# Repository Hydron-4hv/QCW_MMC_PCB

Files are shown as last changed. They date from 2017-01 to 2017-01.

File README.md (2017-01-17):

# QCW_MMC_PCB
PCB for MMC for QCW DRSSTC

- PCB for 12.4nF/6.4kV MMC using 32x 6.2nF/1600V B32672 TDK EPCOS capacitors. Can fit other 15mm lead spacing capacitors (e.g. up to 32x 15nF/1600V in B32672 series, or using every second row, up to 16x 33nF/1600V).
- Suggest using 2x >5Mohm 1206 High Voltage SMD resistors for bleed/balance across each capacitor (footprints provided on underside).
  - Note that when MMC capacitors with rating >~800V are used (and run near their DC rating) it is likely that the resistors will end up having voltage applied greater than their normal "working voltage".
  - "High Voltage" rated resistors are available, and should have an "overload" voltage rating significantly greater than their working voltage.
  - It may be OK to run at the "overload" rating in tesla coil duty, but is at your own risk.
- Footprints provided for optional Wurth Electronics press-fit connectors (assumes HASL PCB finish), as well as various holes for screw-down terminations
- Intended for use by itself (using 1 or more PCBs depending on requirement), or in conjuction with PCBs located in the "GDT_PCB" and "QCW_half_bridge_PCB" repos.

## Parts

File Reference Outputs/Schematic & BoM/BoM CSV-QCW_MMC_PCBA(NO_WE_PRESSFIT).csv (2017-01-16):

Designator | Comment | Description | Fitted | Footprint | LibRef | Quantity
C1, C2, C3, C4, C5, C6, C7, C8, C9, C10, C11, C12, C13, C14, C15, C16, C17, C18, C19, C20, C21, C22, C23, C24, C25, C26, C27, C28, C29, C30, C31, C32 | B32672 | Capacitor | Fitted | B32672 6n2 1600V | Cap | 32
E1, E2, E3, E4 | 7461111 | WP-RAFU 90° with Full Plain Pin Plate, M4, thr 5mm | Not Fitted | 7461111_HAL Surface | WP-RAFU, 7461111 | 0
R1, R2, R3, R4, R5, R6, R7, R8, R9, R10, R11, R12, R13, R14, R15, R16, R17, R18, R19, R20, R21, R22, R23, R24, R25, R26, R27, R28, R29, R30, R31, R32, R33, R34, R35, R36, R37, R38, R39, R40, R41, R42, R43, R44, R45, R46, R47, R48, R49, R50, R51, R52, R53, R54, R55, R56, R57, R58, R59, R60, R61, R62, R63, R64 | HV 1206 Resistor | Resistor | Fitted | RES_1206_HV | Res3 | 64

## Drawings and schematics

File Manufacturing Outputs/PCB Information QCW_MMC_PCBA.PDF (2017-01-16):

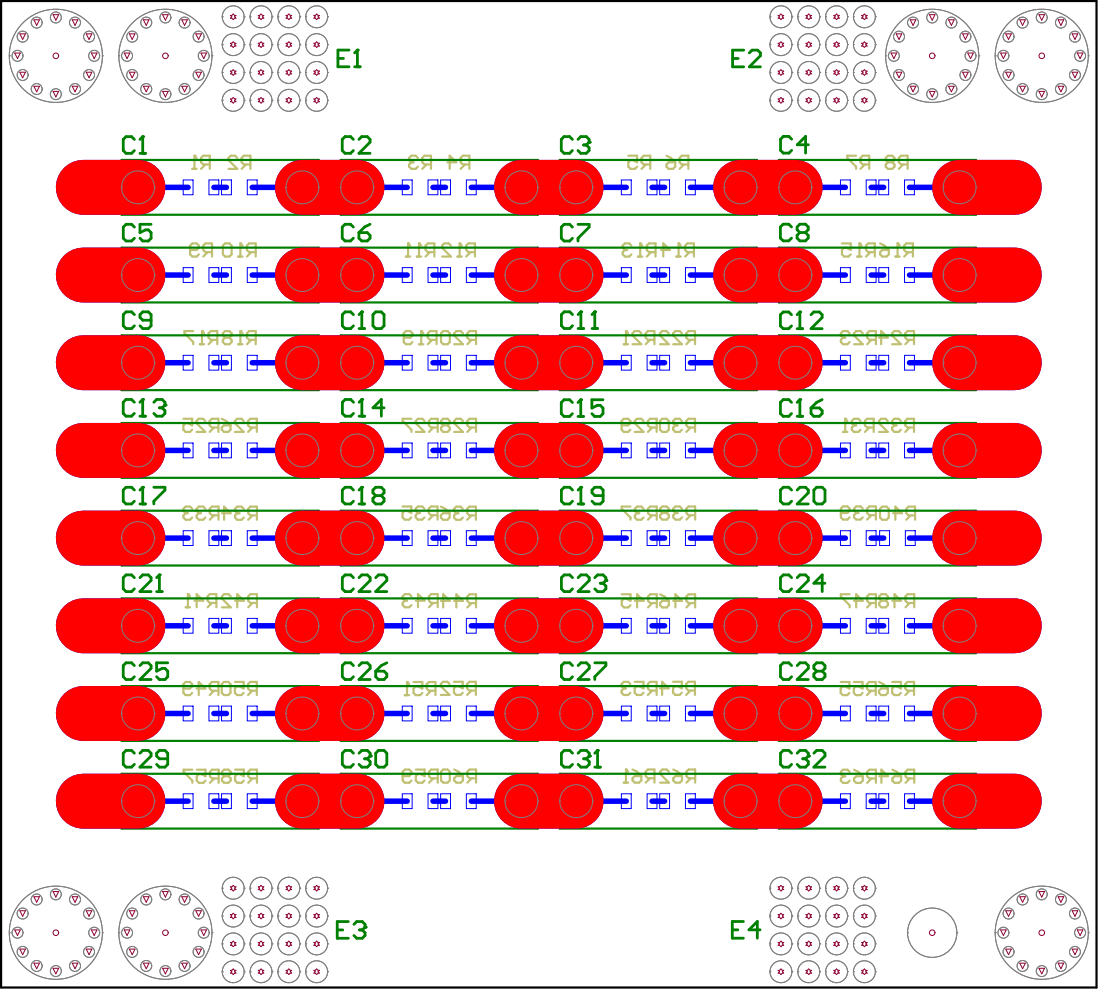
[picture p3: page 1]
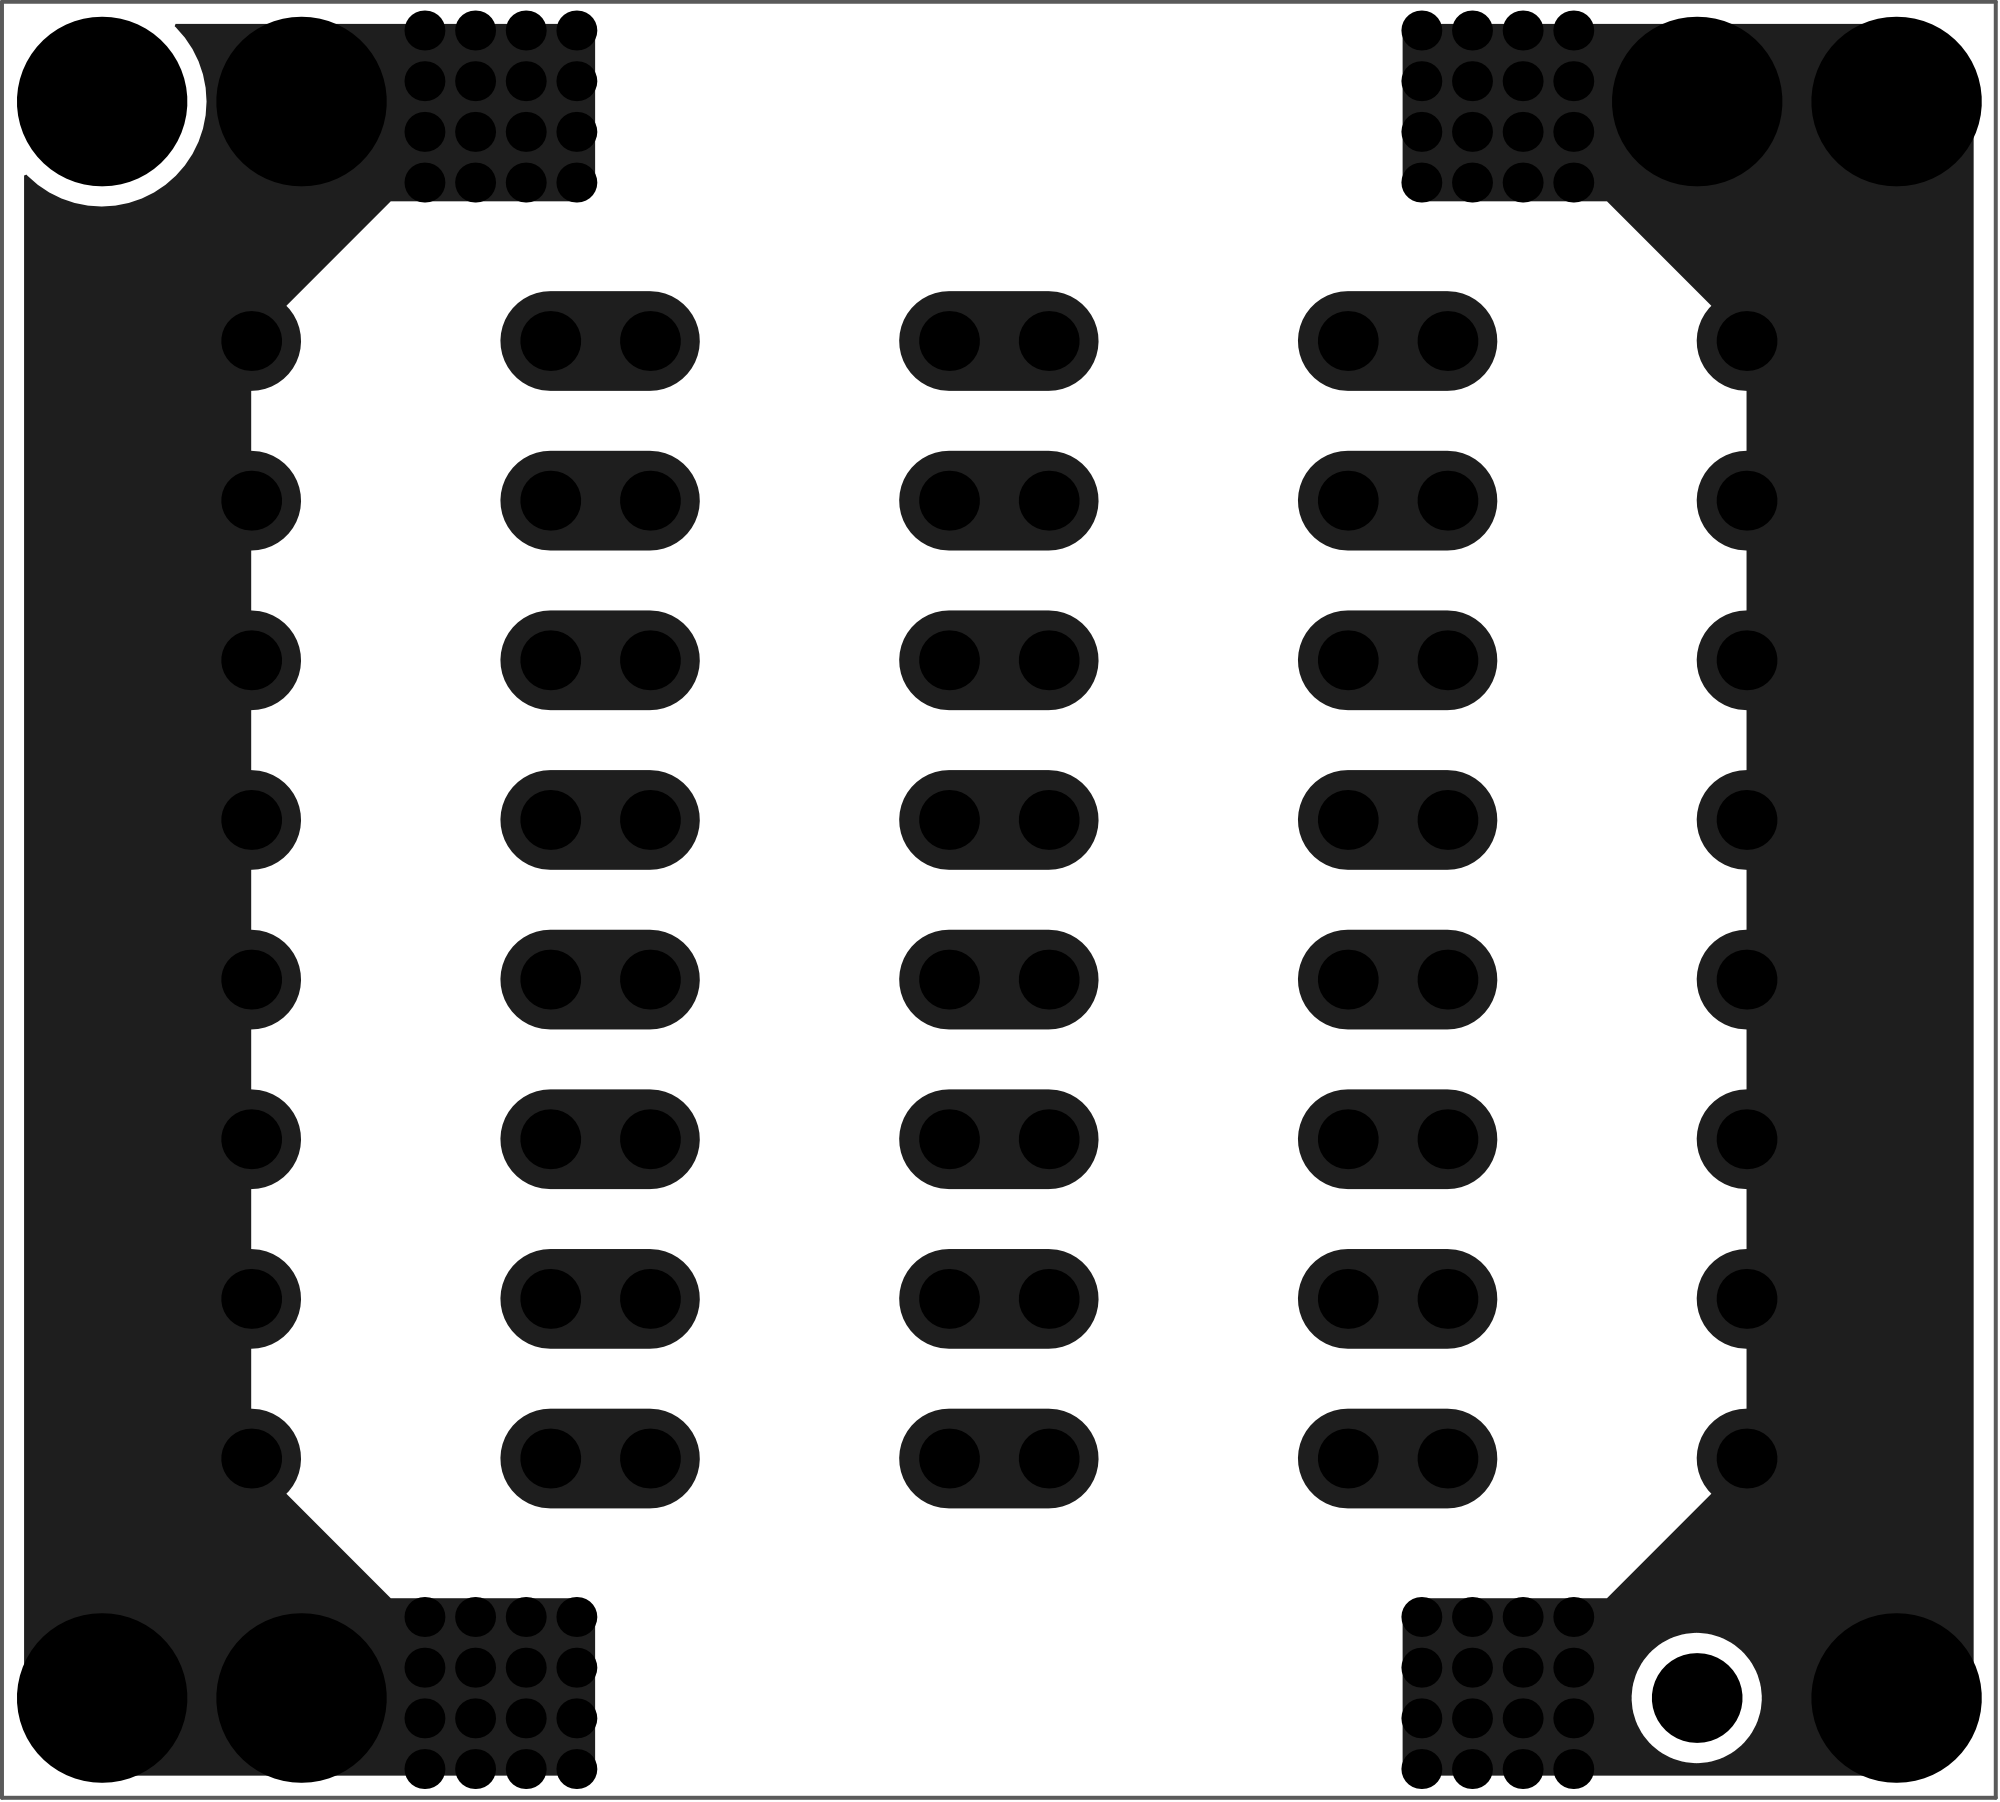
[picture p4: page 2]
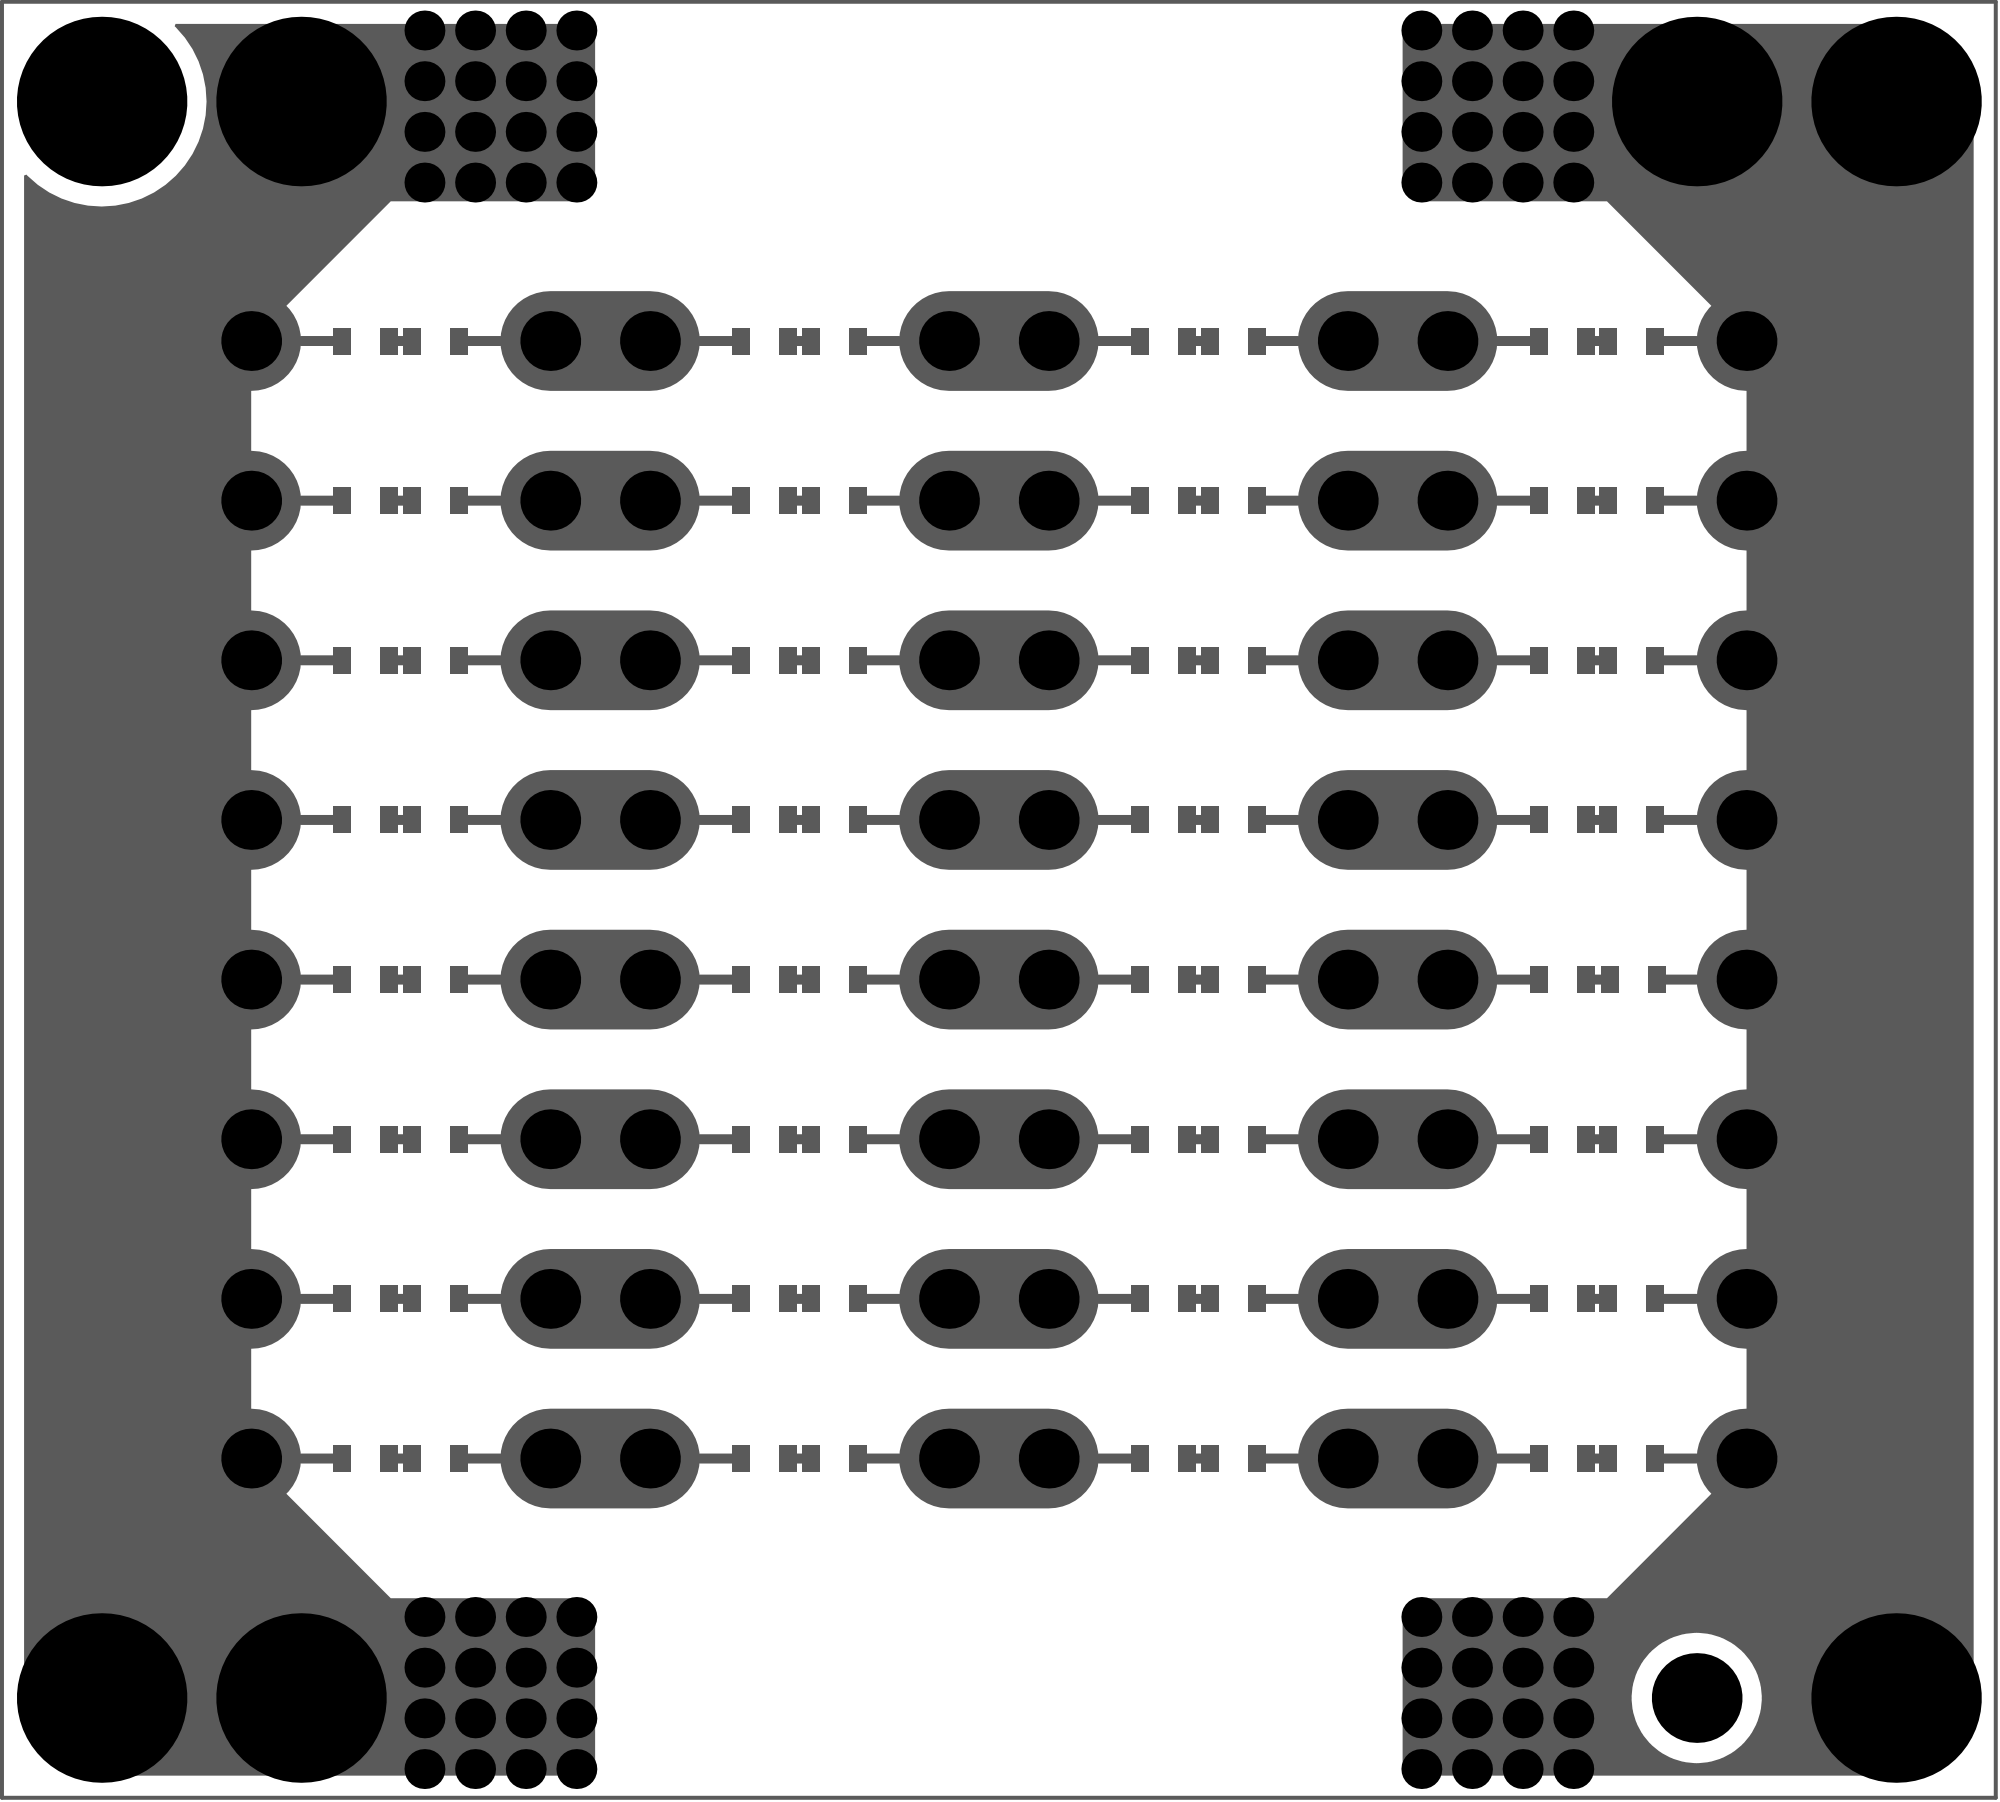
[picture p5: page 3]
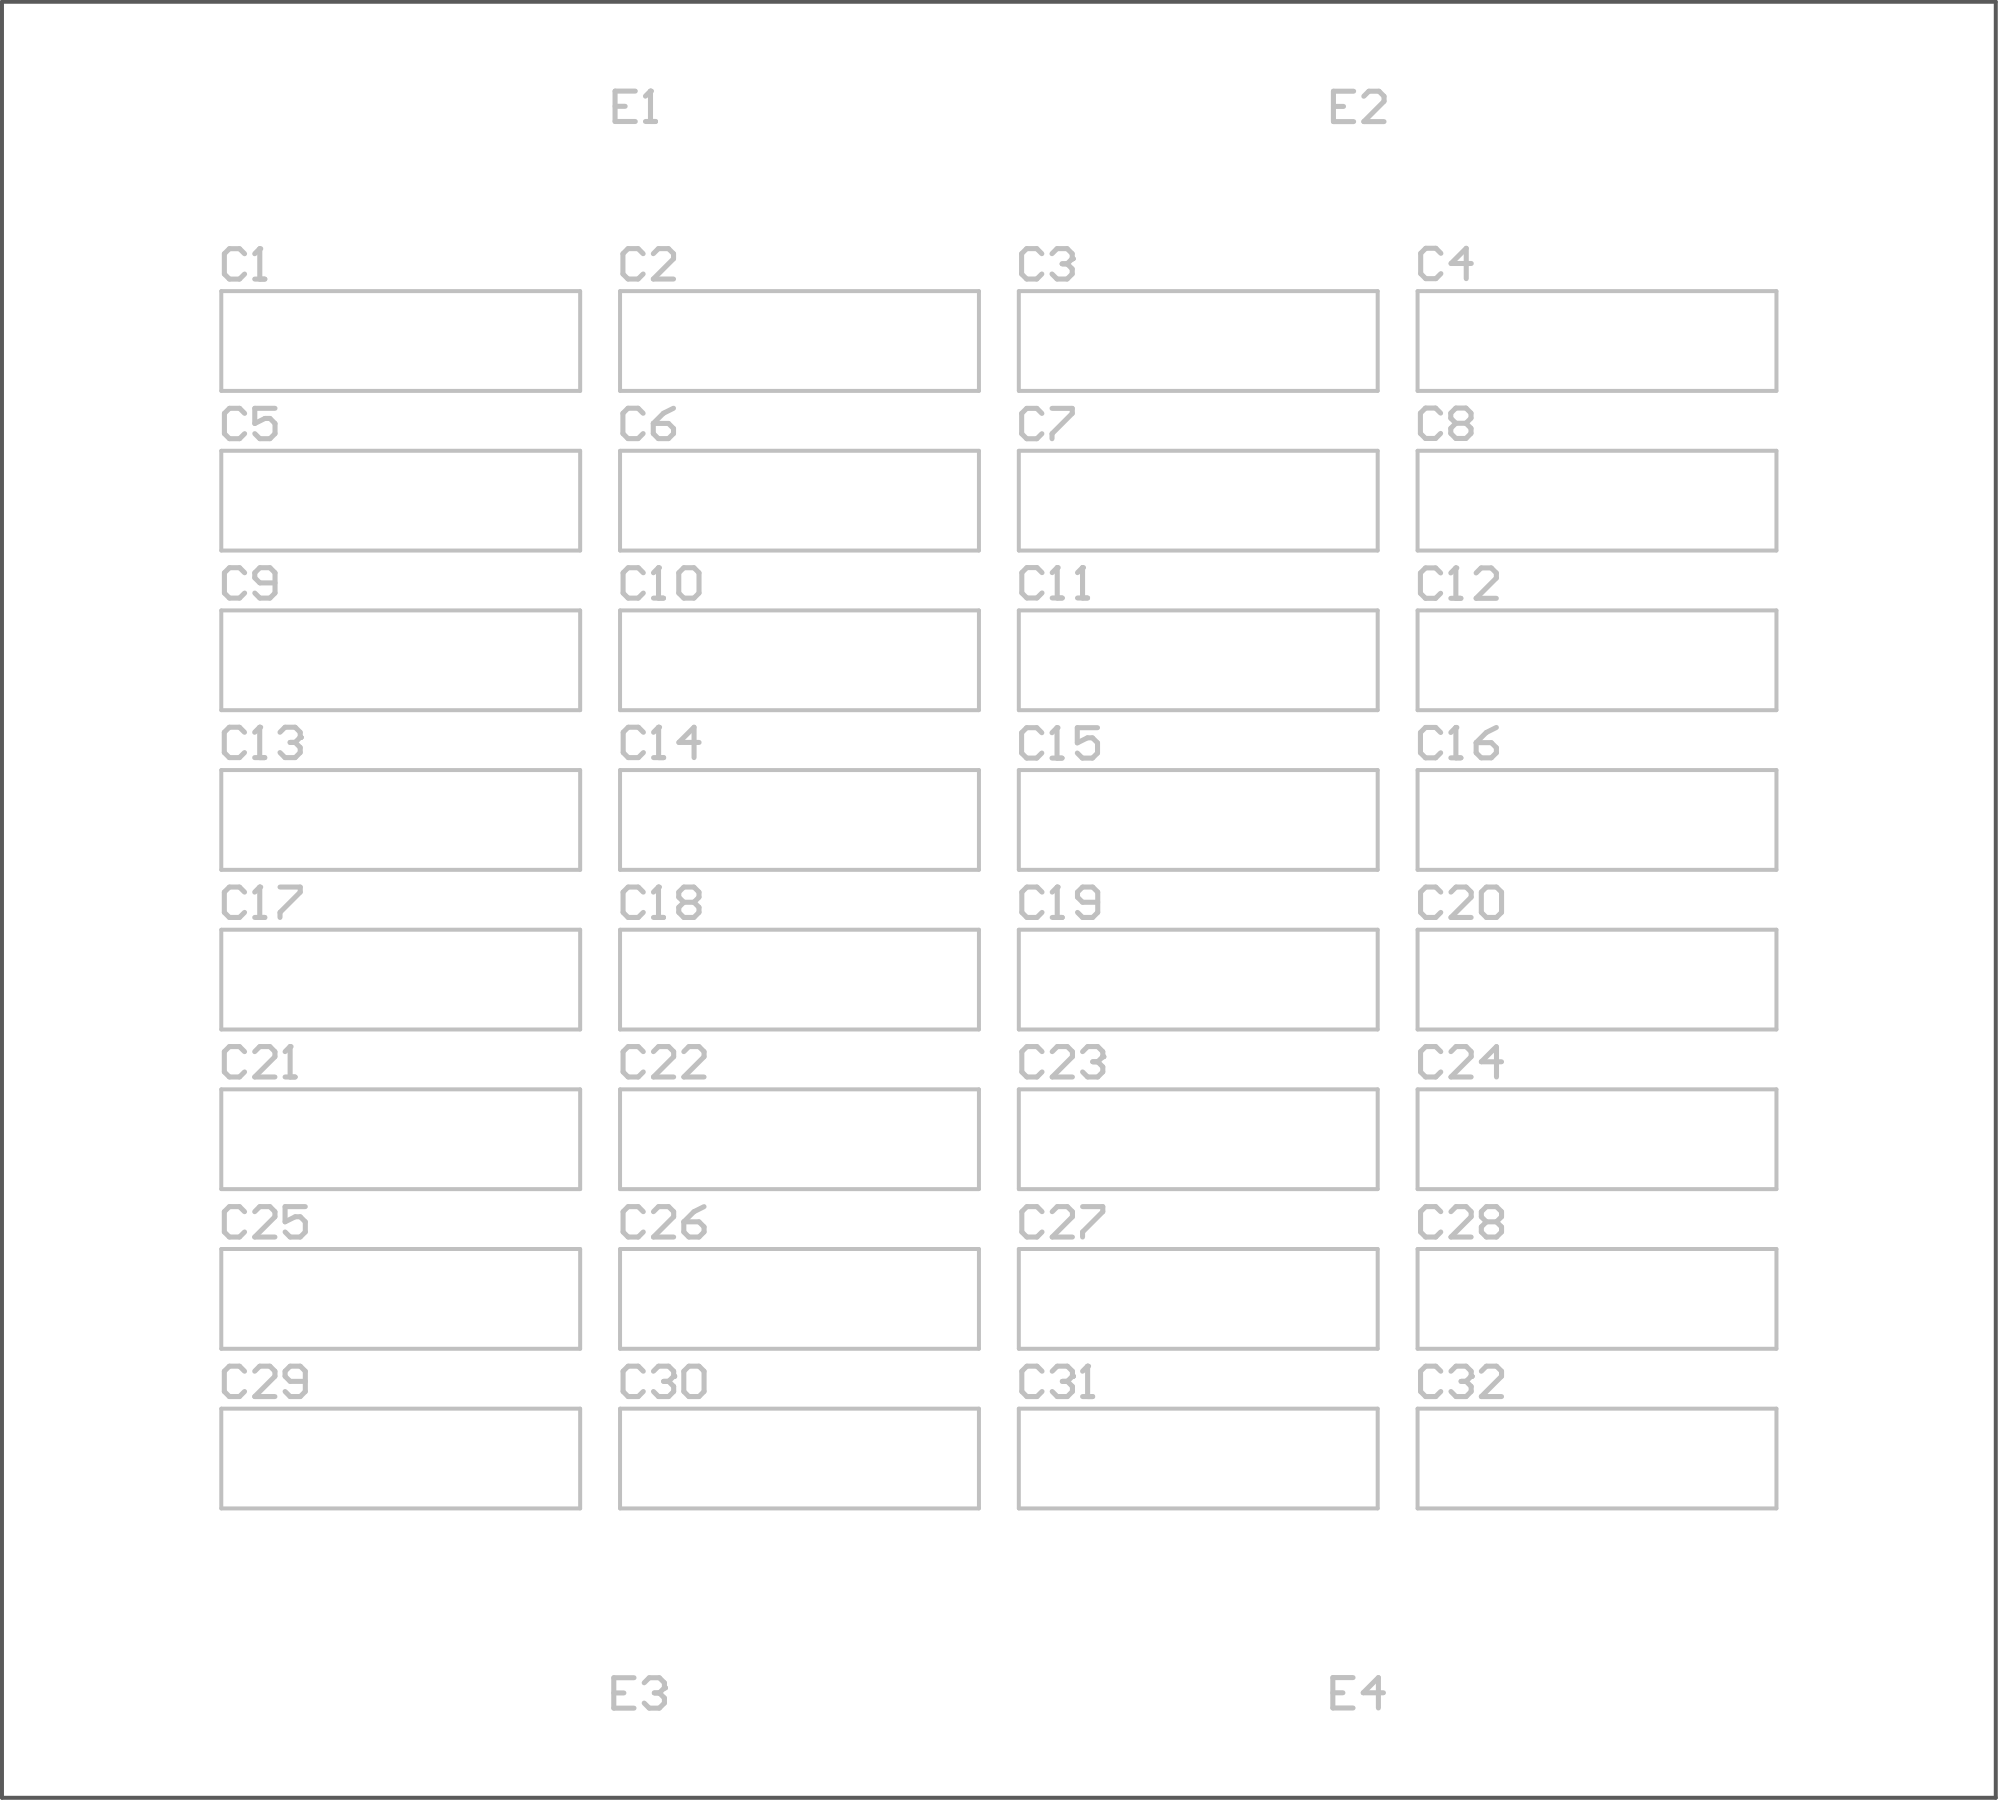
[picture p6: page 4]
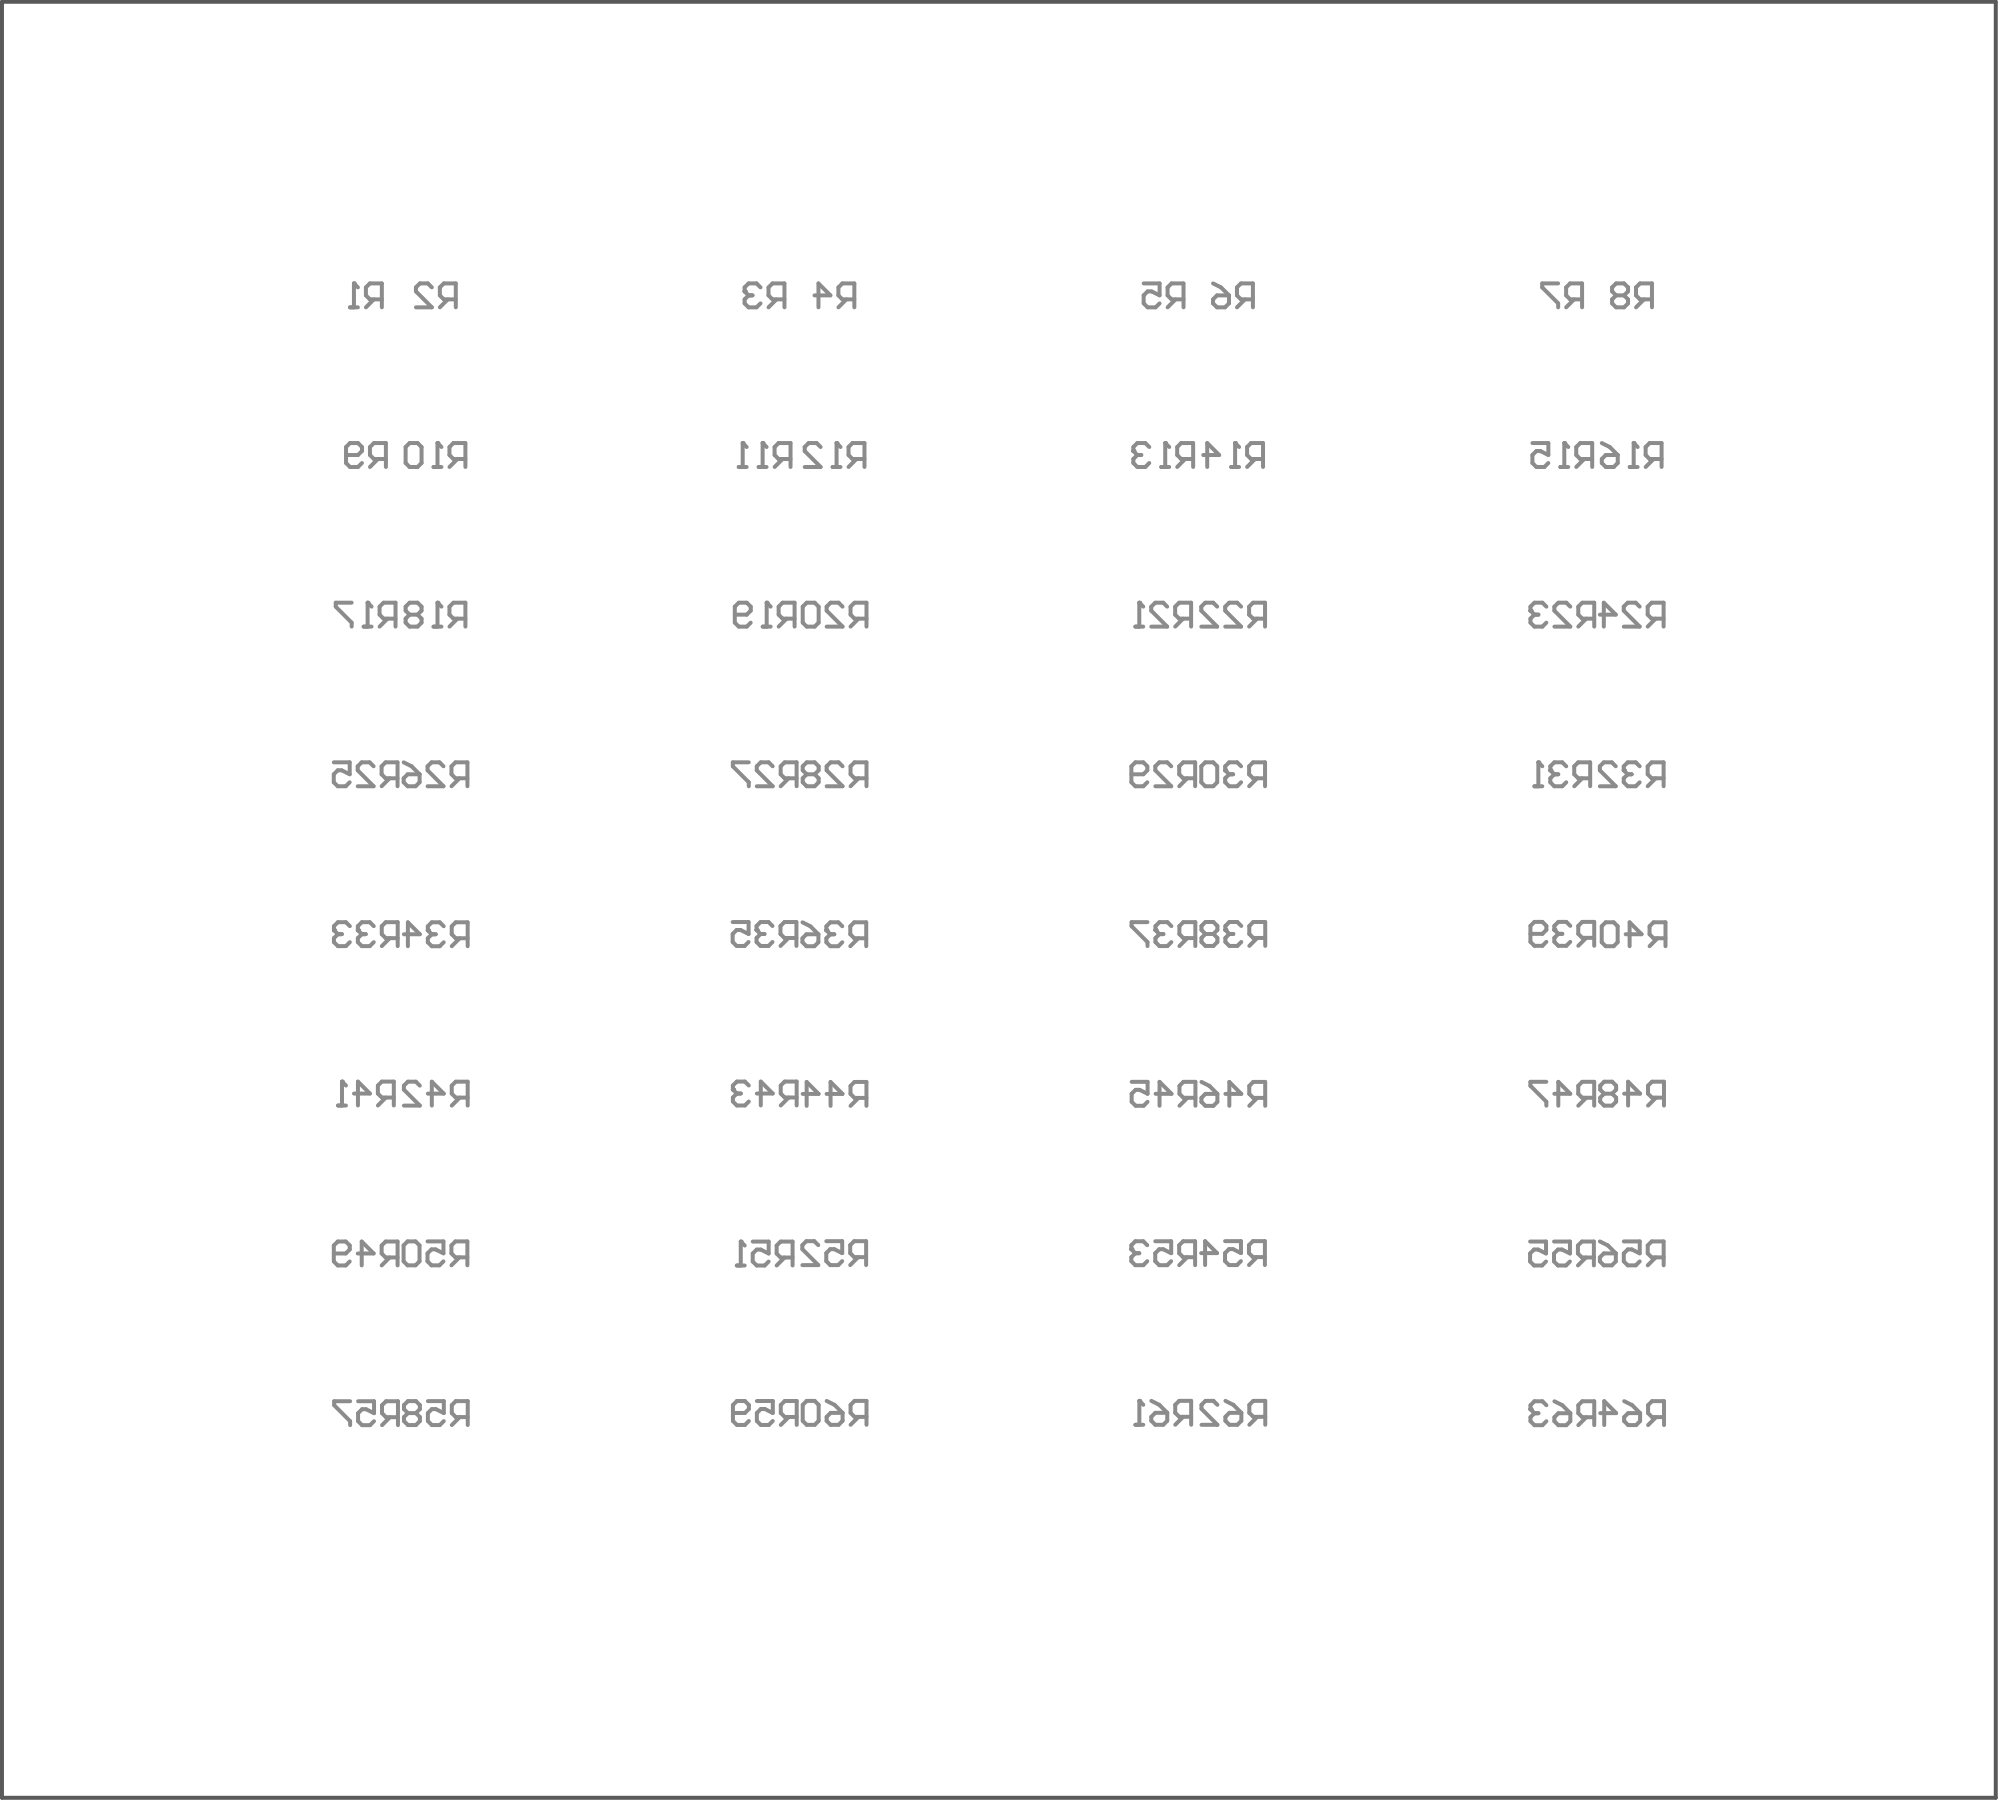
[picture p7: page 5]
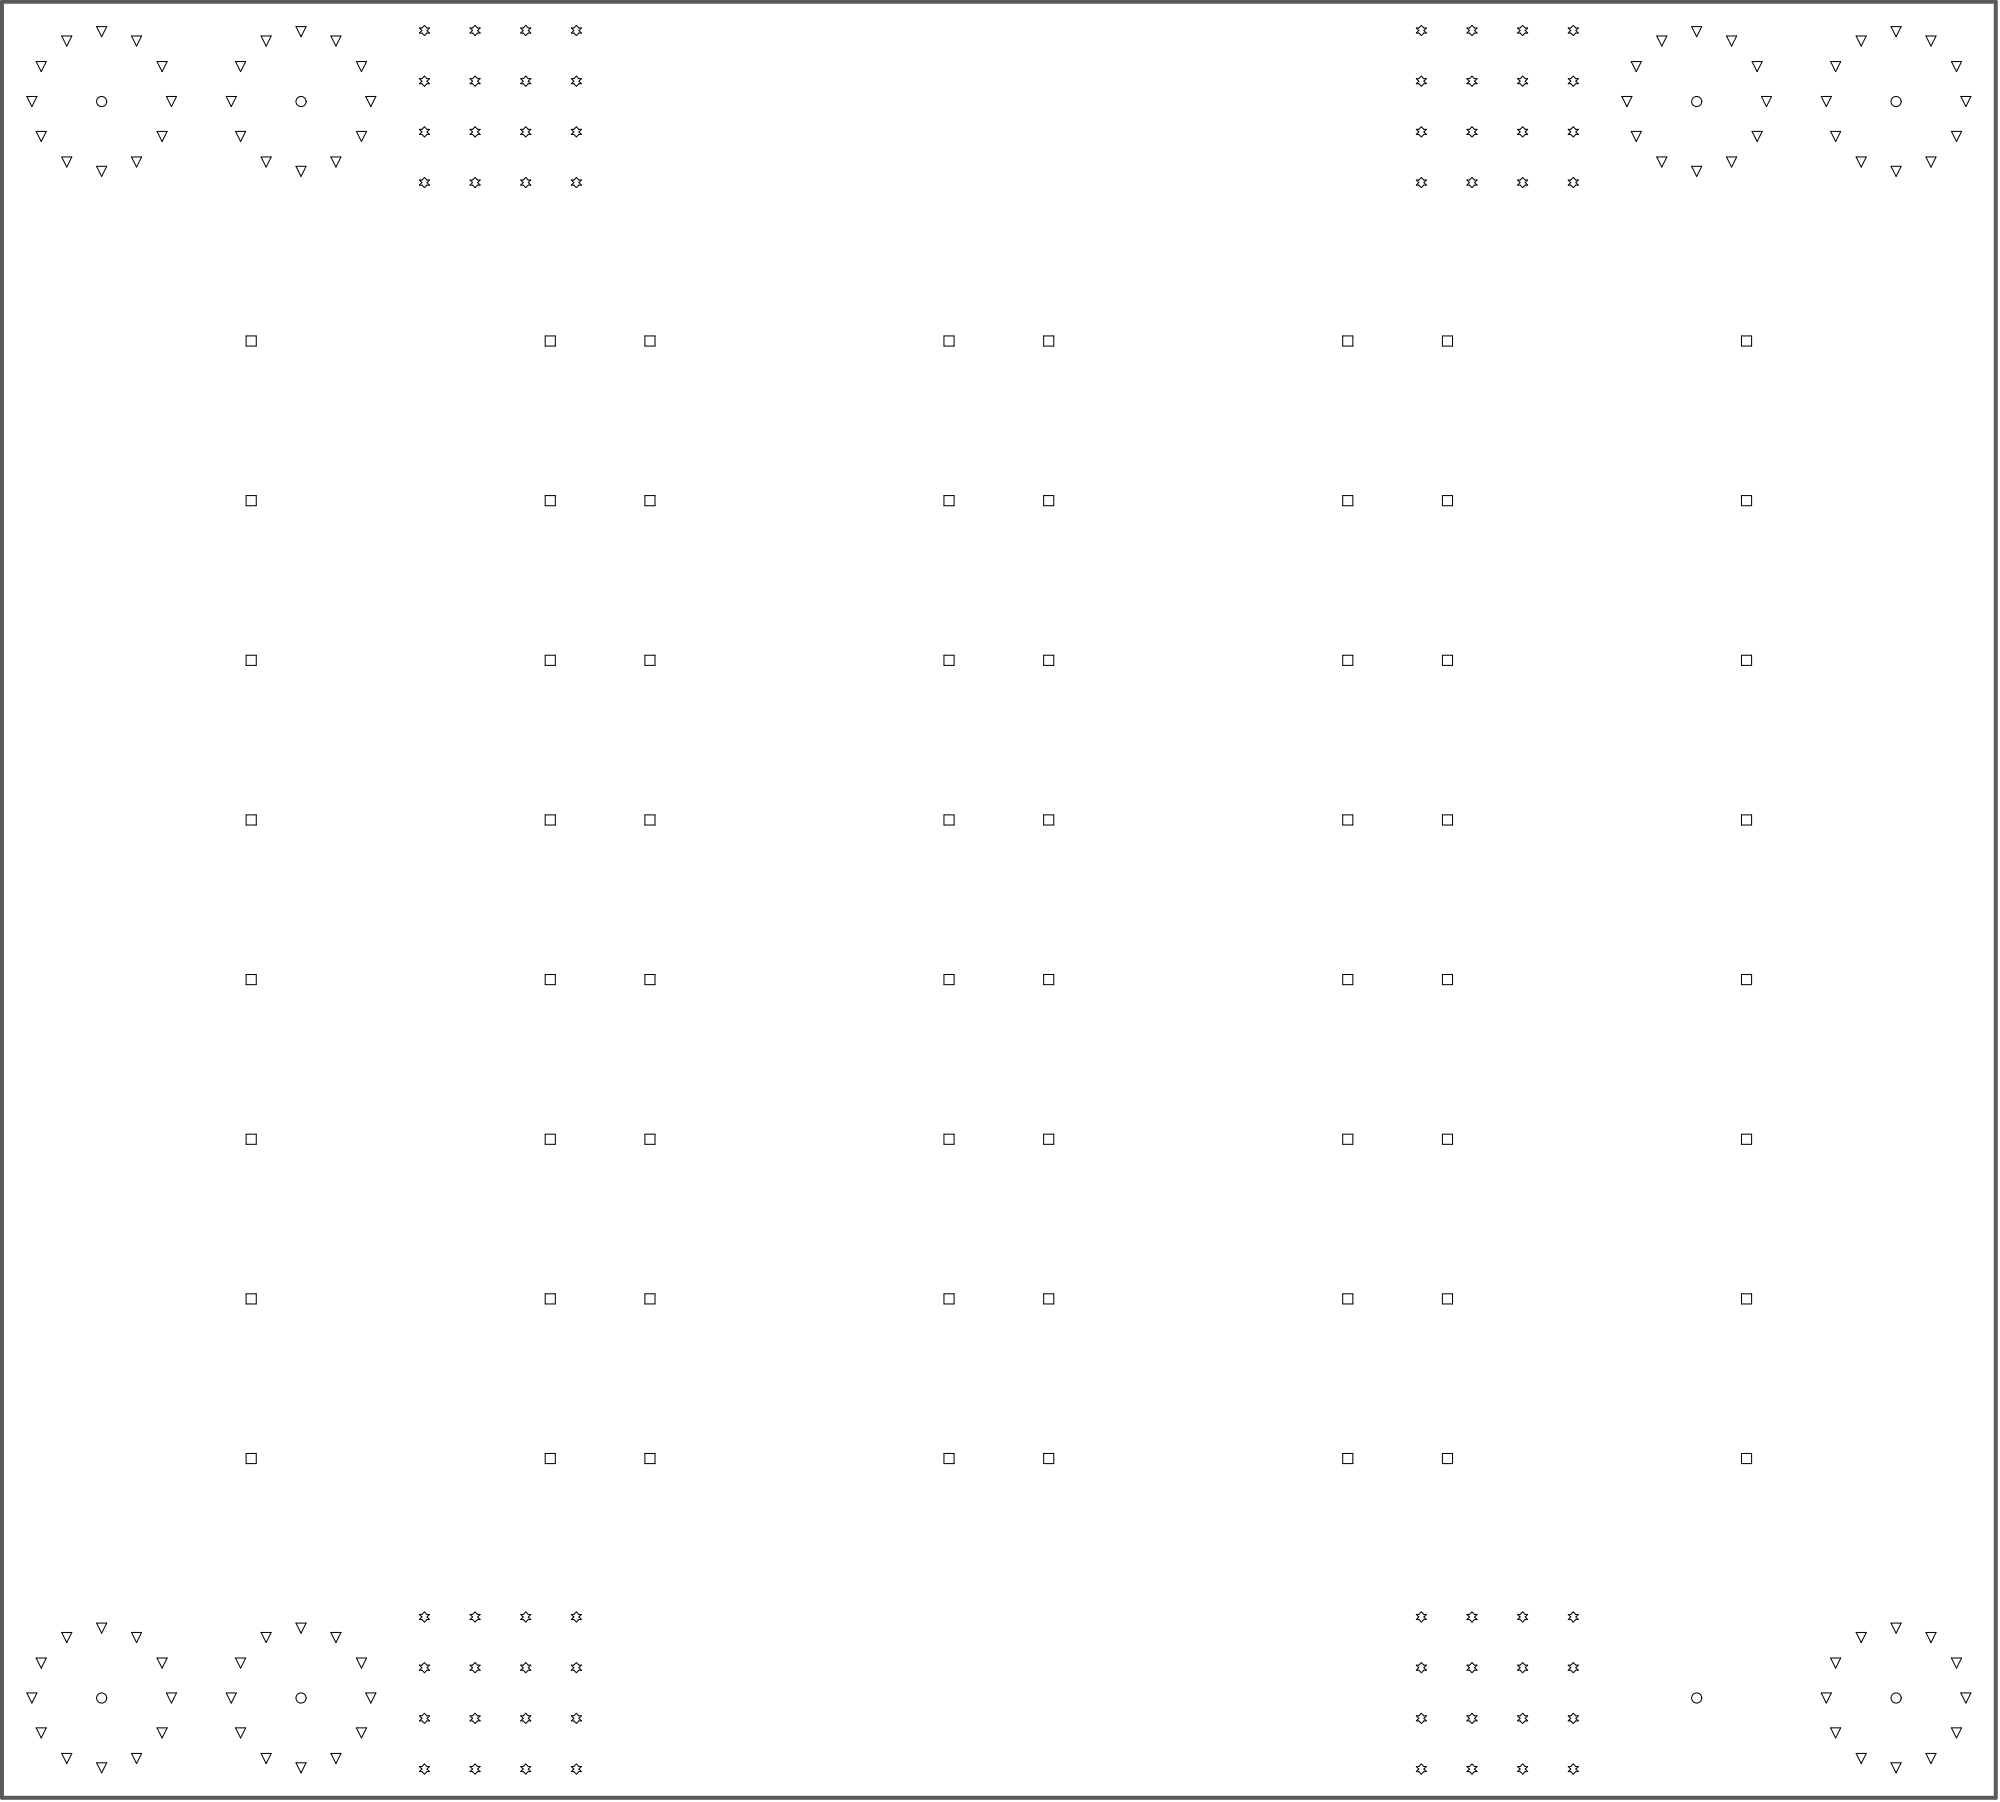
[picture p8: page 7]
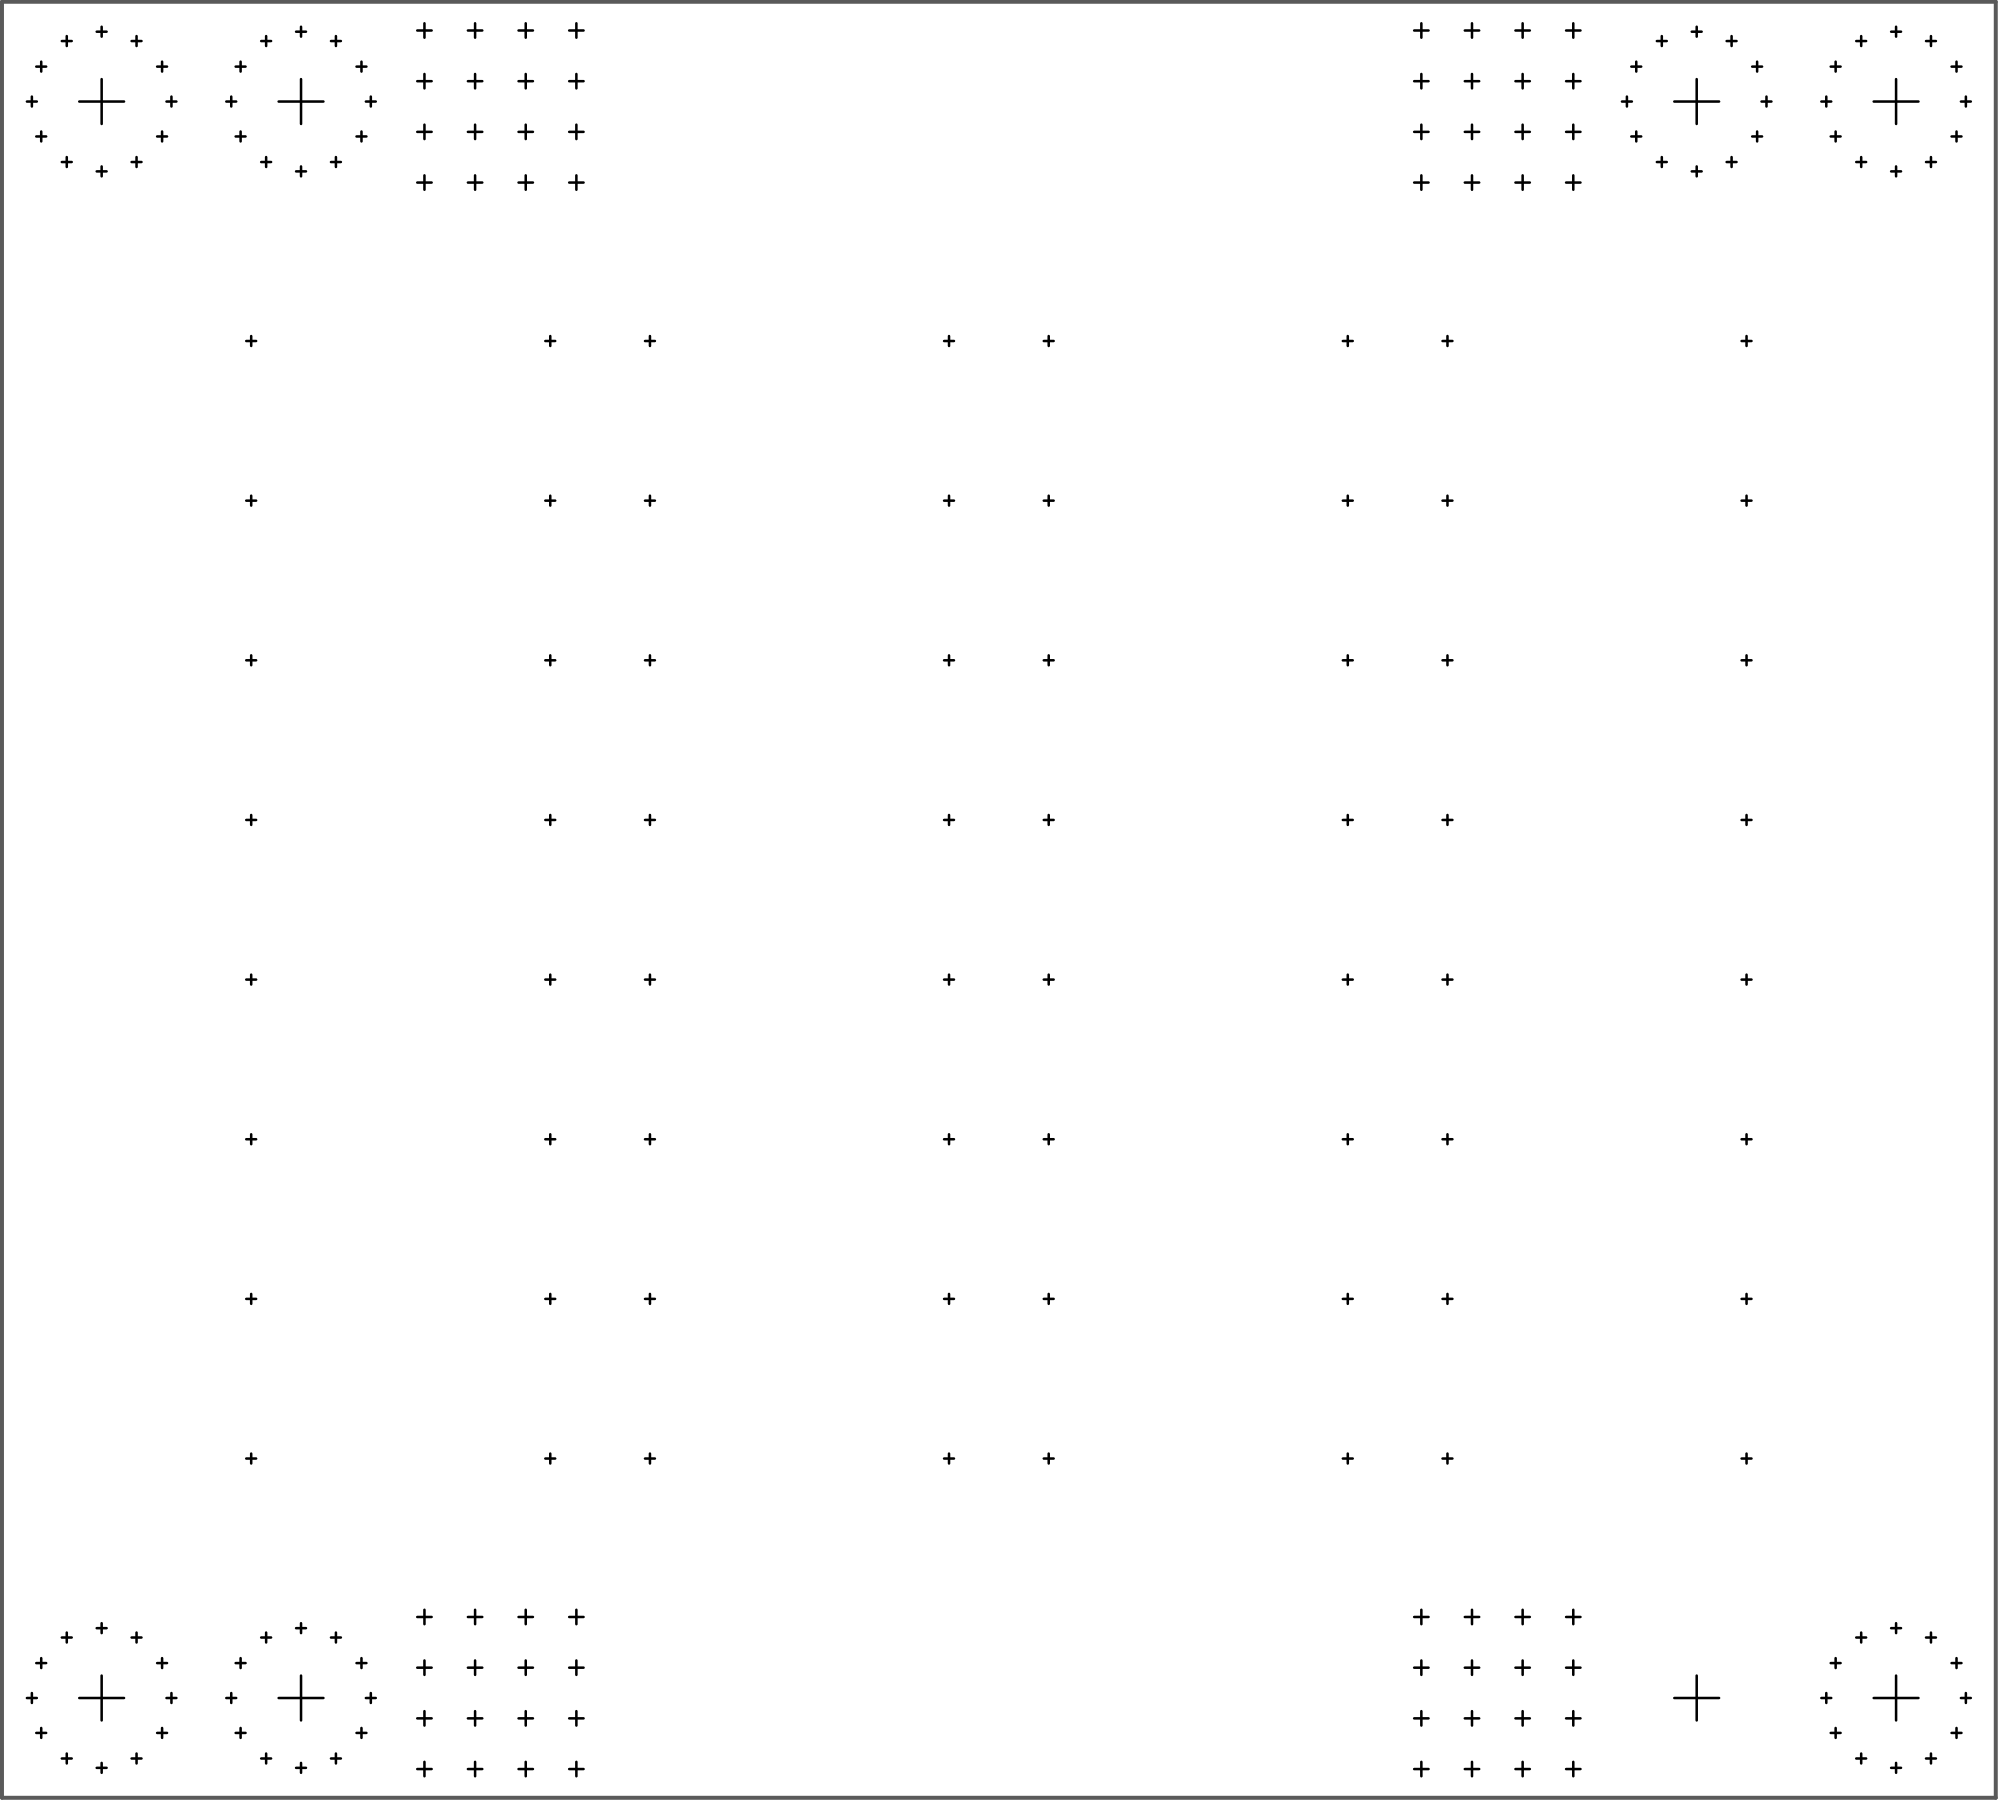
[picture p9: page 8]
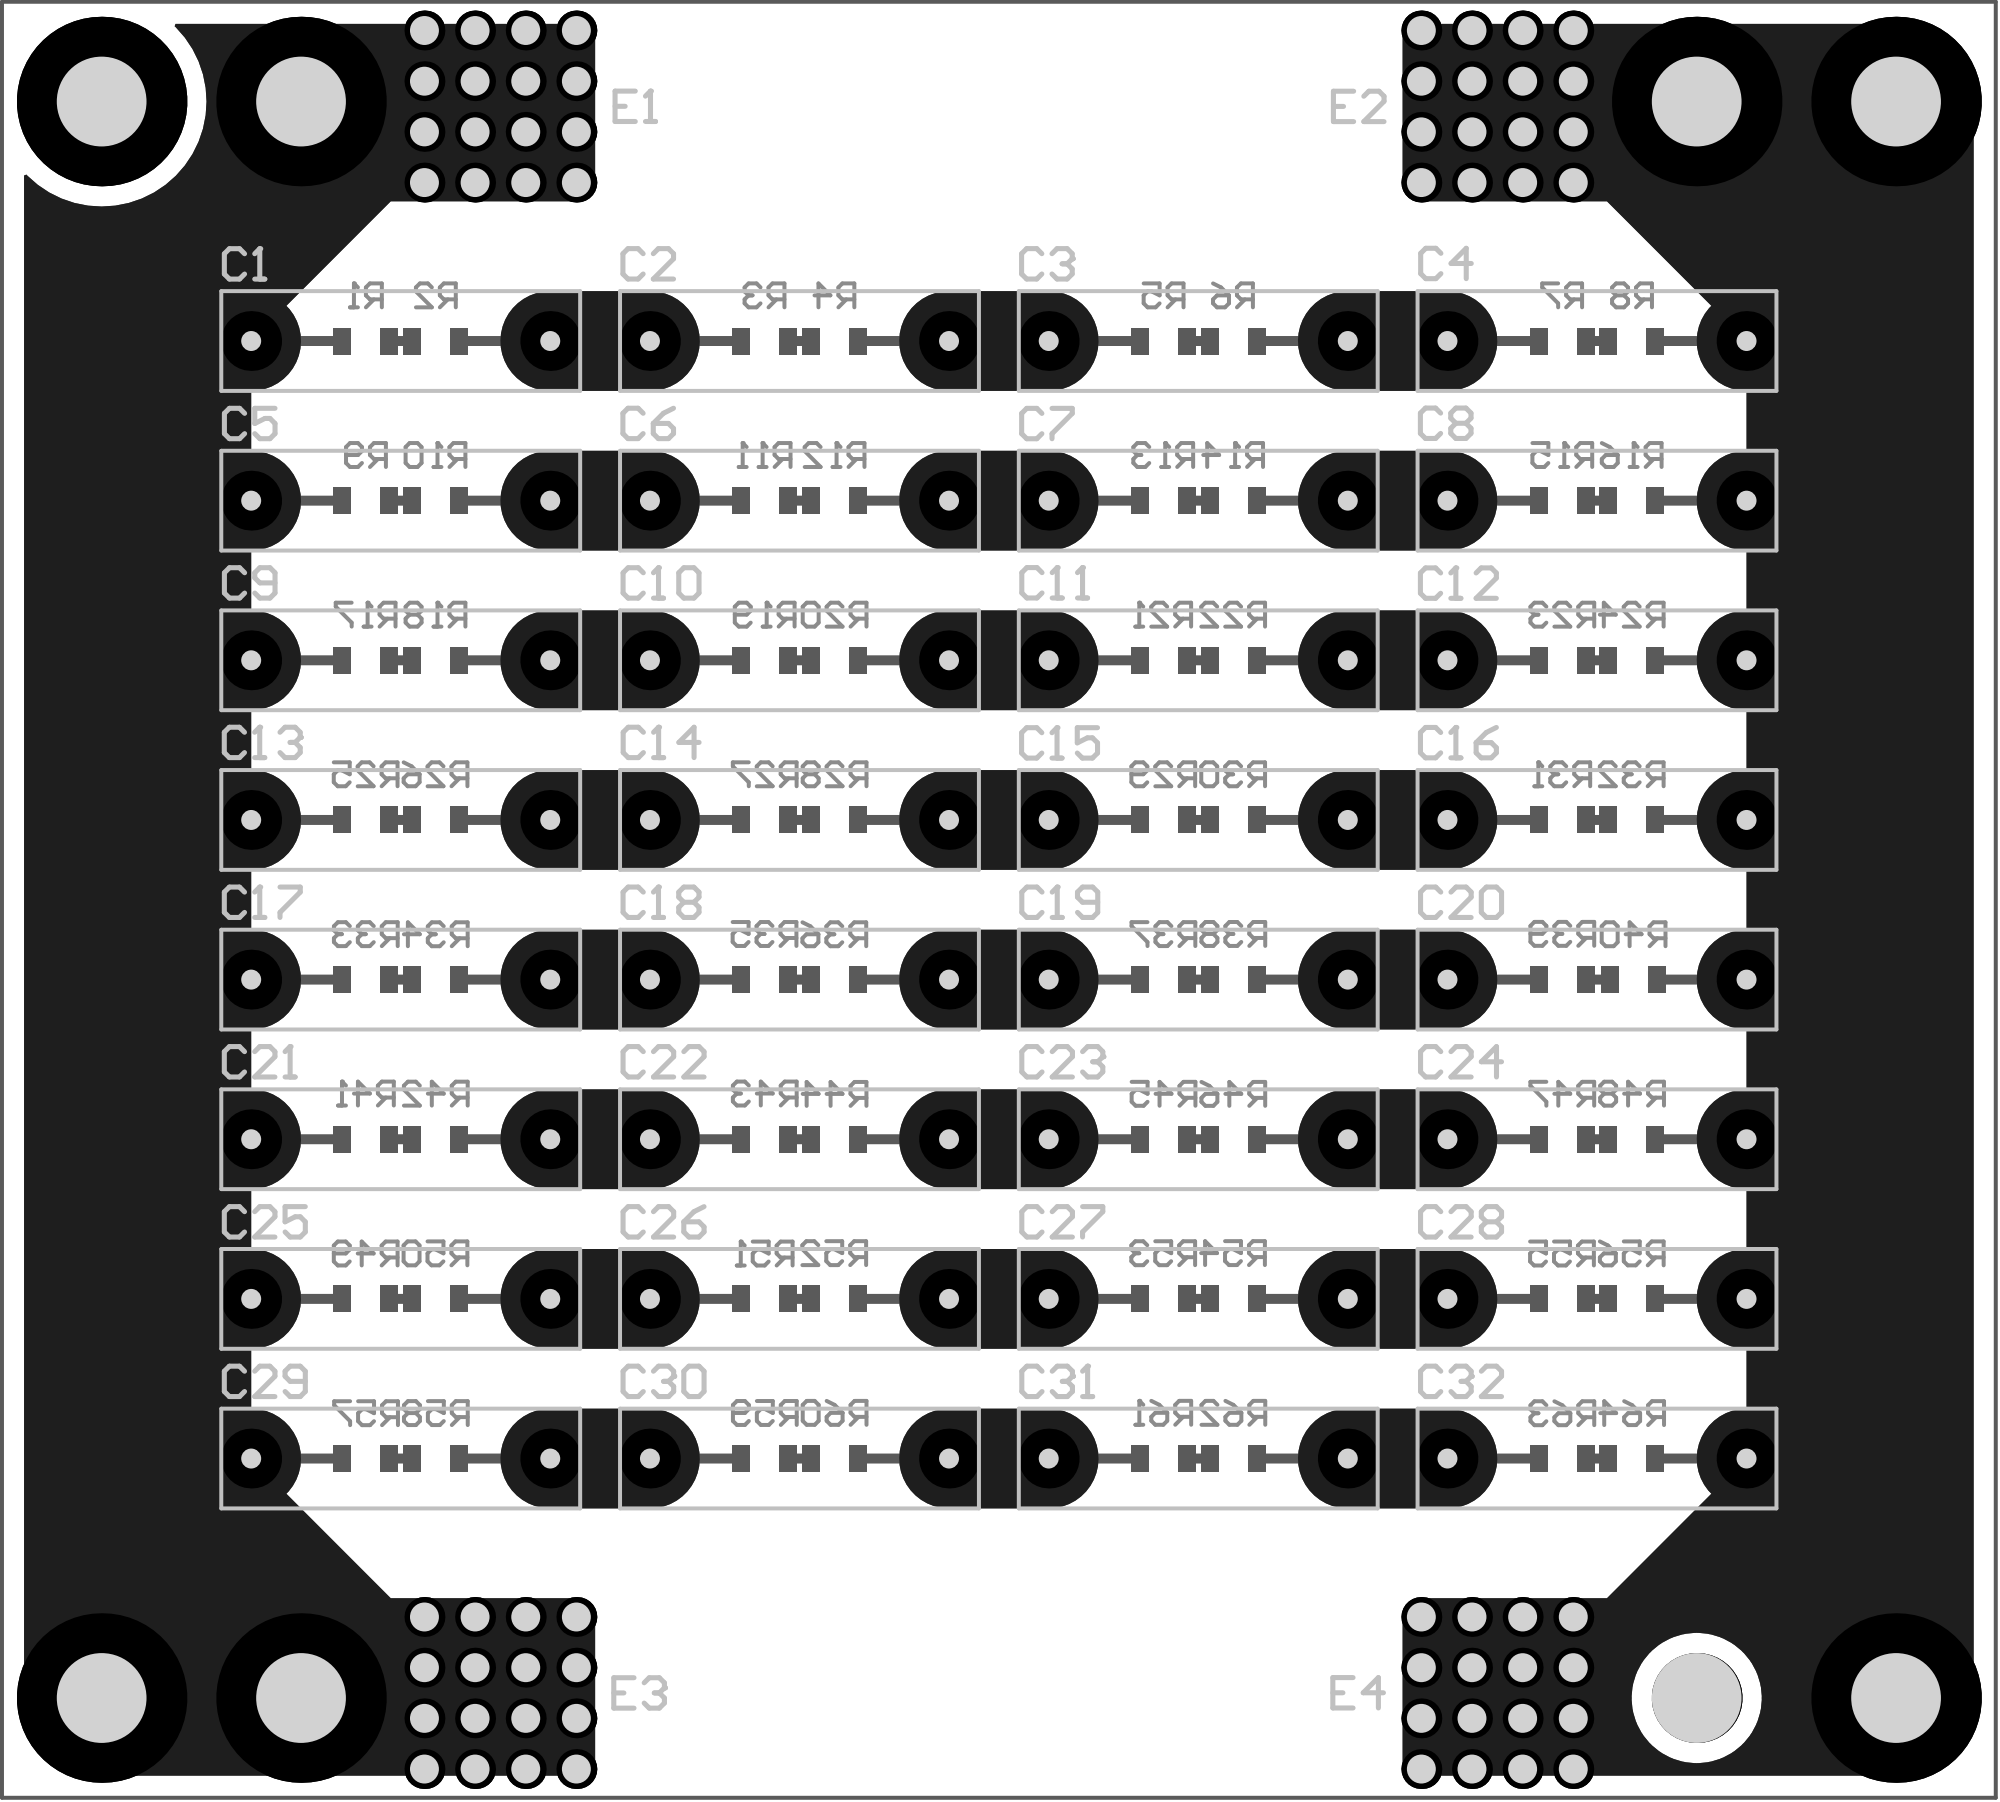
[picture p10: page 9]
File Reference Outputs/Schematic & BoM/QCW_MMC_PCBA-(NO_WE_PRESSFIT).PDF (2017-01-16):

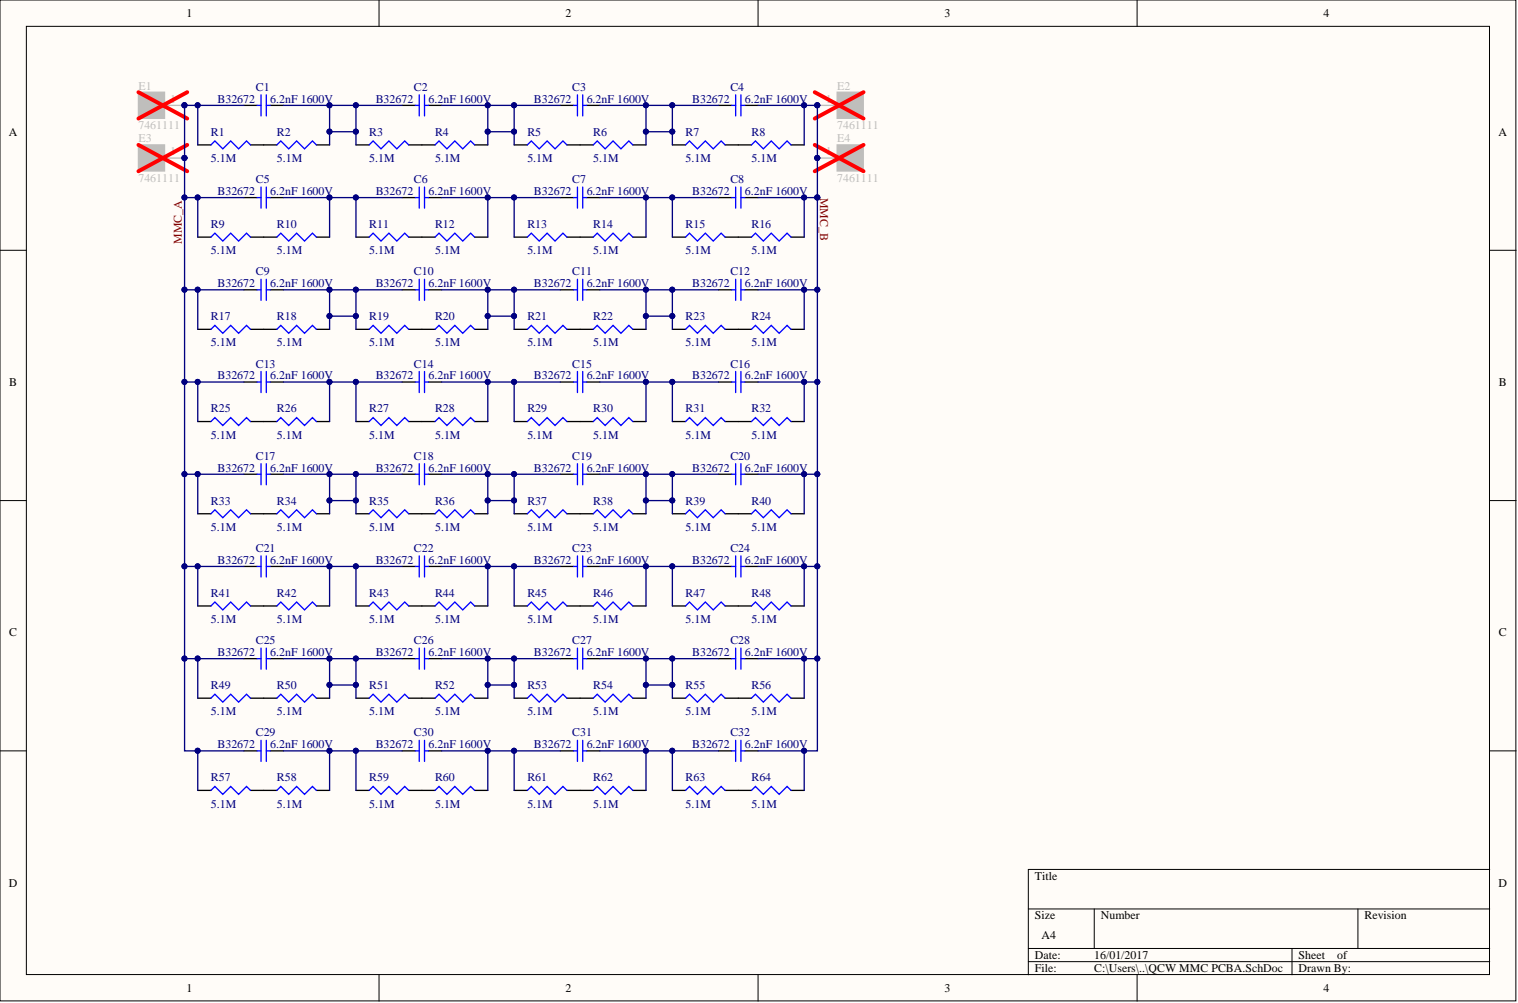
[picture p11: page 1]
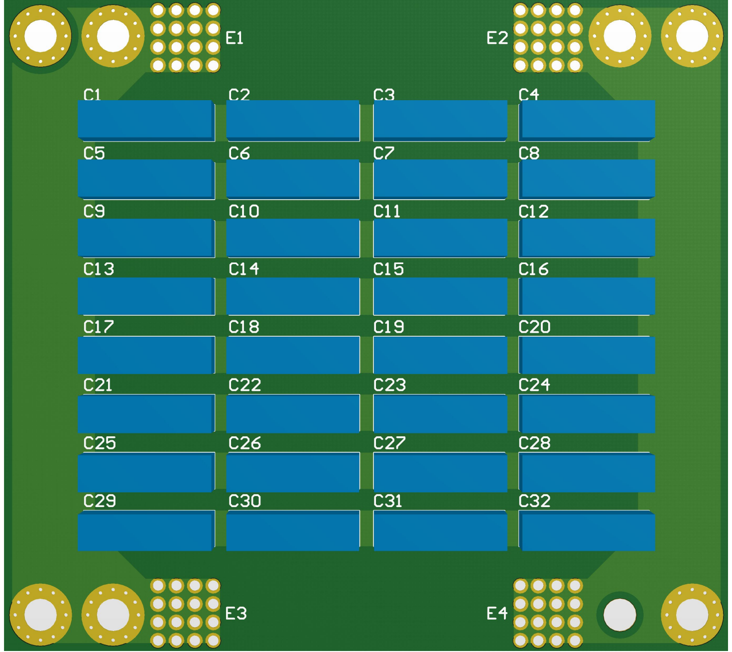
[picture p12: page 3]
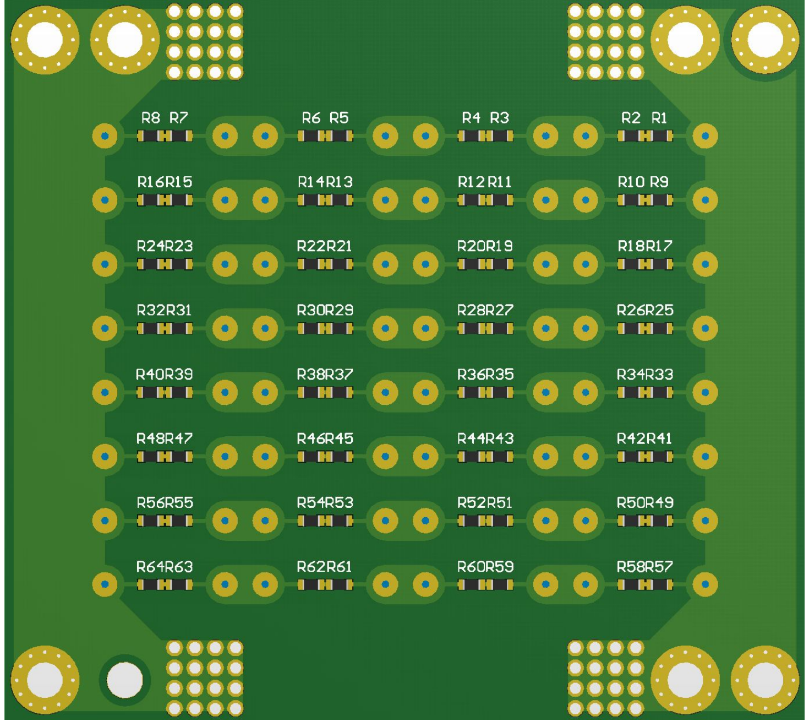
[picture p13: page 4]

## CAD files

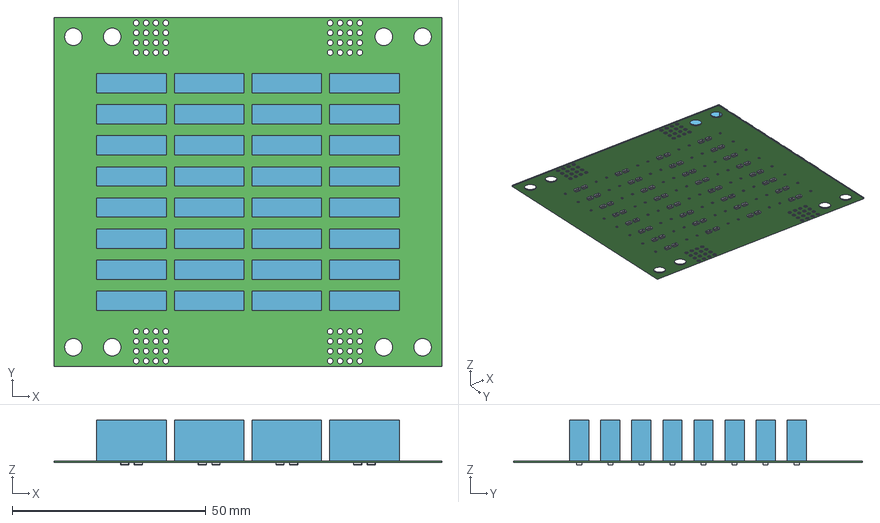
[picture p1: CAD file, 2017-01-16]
Reference Outputs/Mechanical/Export STEP Model of complete PCB_QCW_MMC_PCBA-(NO_WE_PRESSFIT).step
100.0 x 90.0 x 11.6 mm
BoardQCW_MMC_PCBA
Extruded x 32
Mid_Body x 64
Open_CASCADE_STEP_translator_6.8_1.2.1 x 128
Mark x 64

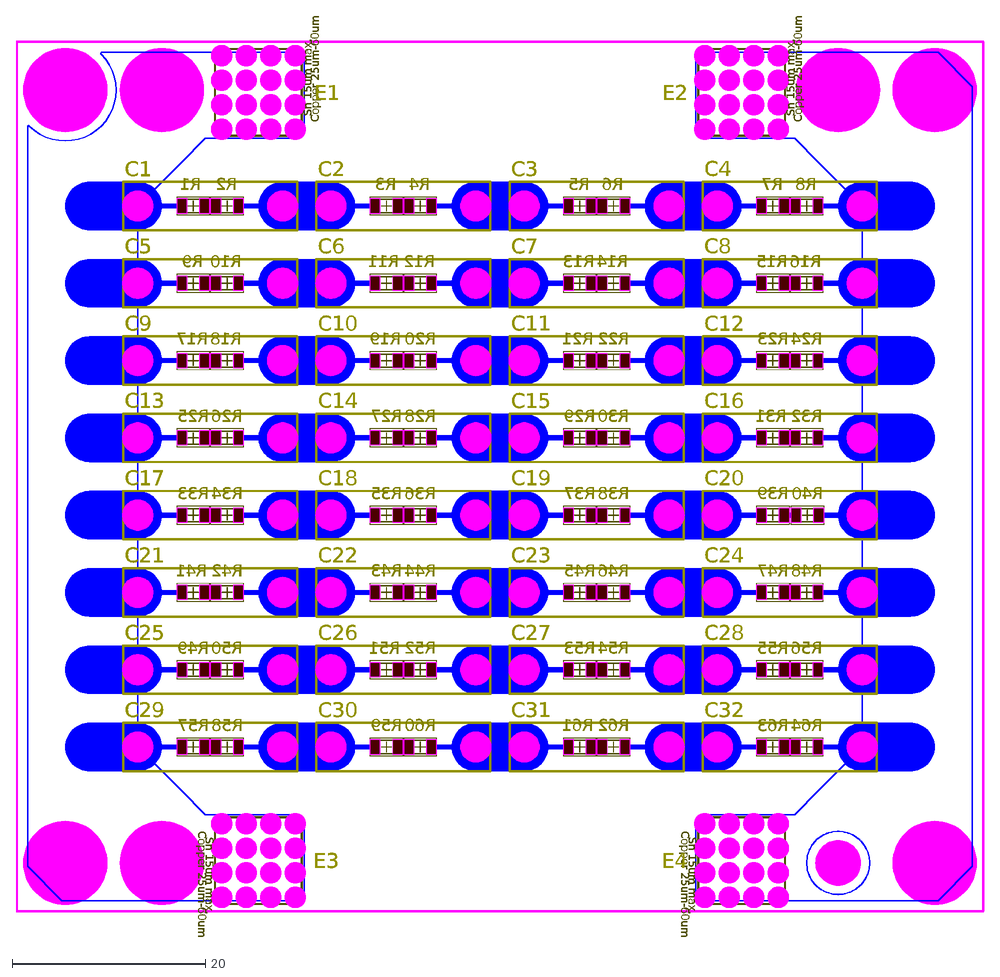
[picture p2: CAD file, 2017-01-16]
Reference Outputs/Mechanical/QCW MMC PCBA.DXF
C32
C31
C30
C29
C28
C27
C26
C25
C24
C23
C22
C21
C20
C19
C18
C17
C16
C15
C14
C13
C12
C11
C10
C9
C8
C7
C6
C5
C4
C3
C2
C1
R1
R2
R3
R4
R5
R6
R7
R8
R9
R10
R11
R12
R13
R14
R15
R16
R17
R18
R19
R20
R21
R22
R23
R24
R25
R26
R27
R28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
